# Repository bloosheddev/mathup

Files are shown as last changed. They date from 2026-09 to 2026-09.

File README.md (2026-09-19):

<h1 align="center">
  <picture>
    
  </picture>

<p>
  🔥 MathUp! Clock 🔥
</p>



</h1>

## 💀 Uniques Features!
X + Y = ??? (answer to snooze!!11!!1!)

## 💀 Overall Case!
| Top View | Bottom View |
| - | - |
|  | 

## ✍️ Schematic Image!


## 🖼️ PCB!

| 2D View | 3D View |
| - | - |
|  |  |

## Case Part!

| Lid | Case Chassis |
| - | - |
|  |  |
| The lid will be connected to the main case using strong adhesive to keep it minimalist and having a clean design | The PCB and all the main parts will be mounted on 3 mountings using M3 screws and for the LCD will be mounted on the case's dedicated slot for the LCD |

## Bill of Materials!
| Reference | Qty | Value |
| - | - | - |
| BZ1 | 1 | Buzzer |
| J1 | 1 | Conn_01x08_Pin |
| SW1,SW2,SW3,SW4 | 4 | SW_Push |
| U1 | 1 | XIAO-ESP32-C3-SMD |
| | 12 | MX-Style Keyboard Switches |
| | 4 | White Blank DSA Keycaps |
| | 1 | 2.25in TFT Screen |
| | 1 | 3.3V Piezo Buzzer |
| | 1 | 2.54mm 8 Pin Male Header |
| | 8 | 20cm Female-Female Jumper Wires |
| | 4 | M3x5x4 Heatset Inserts |
| | 4 | M3x8mm Screws |

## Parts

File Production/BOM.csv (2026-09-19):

Reference | Qty | Value | DNP | Exclude from BOM | Exclude from Board | Exclude from Simulation | Exclude from Position Files | Footprint | Datasheet
BZ1 | 1 | Buzzer |  |  |  |  | ${EXCLUDE_FROM_POS_FILES} | Buzzer_Beeper:Buzzer_12x9.5RM7.6
J1 | 1 | Conn_01x08_Pin |  |  |  |  | ${EXCLUDE_FROM_POS_FILES} | Connector_PinSocket_2.54mm:PinSocket_1x08_P2.54mm_Vertical
SW1,SW2,SW3,SW4 | 4 | SW_Push |  |  |  |  | ${EXCLUDE_FROM_POS_FILES} | Button_Switch_Keyboard:SW_Cherry_MX_1.00u_PCB
U1 | 1 | XIAO-ESP32-C3-SMD |  |  |  |  | ${EXCLUDE_FROM_POS_FILES} | Seeed_Studio_XIAO_Series:XIAO-ESP32-C3-DIP
 | 12 | MX-Style Keyboard Switches
 | 4 | White Blank DSA Keycaps
 | 1 | 2.25in TFT Screen
 | 1 | 3.3V Piezo Buzzer
 | 1 | 2.54mm 8 Pin Male Header
 | 8 | 20cm Female-Female Jumper Wires
 | 4 | M3x5x4 Heatset Inserts
 | 4 | M3x8mm Screws

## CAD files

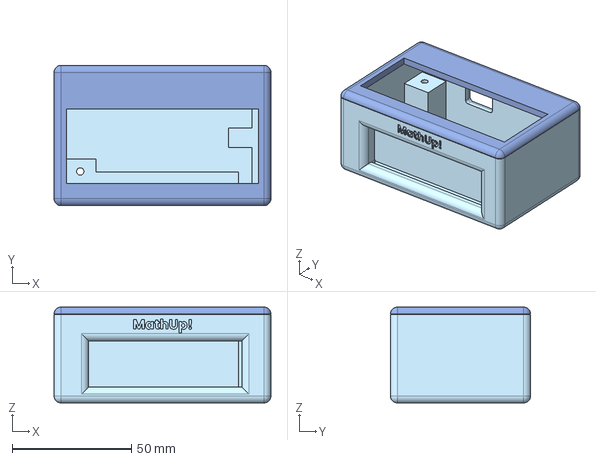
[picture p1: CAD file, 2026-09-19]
CAD/CASE_ONLY.step
91.0 x 58.9 x 40.2 mm

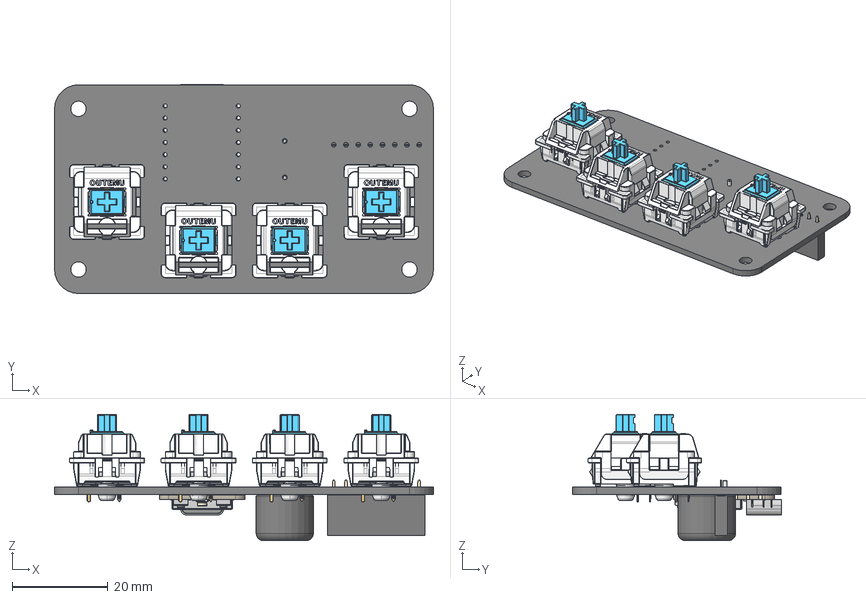
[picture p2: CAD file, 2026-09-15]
MUC_PCB/MUC_PCB.step
79.0 x 43.6 x 26.3 mm
BOTT x 4
PIN x 4
SPRIN x 4
CLICK x 4
RET x 4
TOP x 4
BOSS-EXTRUDE14_8_
BOSS-EXTRUDE7_4_
BOSS-EXTRUDE7_3_
BOSS-EXTRUDE14_4_
BOSS-EXTRUDE14_2_
BOSS-EXTRUDE14_11_
BOSS-EXTRUDE7_7_
BOSS-EXTRUDE14_9_
BOSS-EXTRUDE14_3_
BOSS-EXTRUDE14_7_
MIRROR2
BOSS-EXTRUDE14_5_
BOSS-EXTRUDE14_12_
BOSS-EXTRUDE7_8_
BOSS-EXTRUDE7_1_
BOSS-EXTRUDE14_10_
BOSS-EXTRUDE7_9_
BOSS-EXTRUDE14_6_
BOSS-EXTRUDE14_1_
BOSS-EXTRUDE7_6_
BOSS-EXTRUDE7_2_
CUT-EXTRUDE5
BOSS-EXTRUDE7_5_
U.FL Connector v1
Button (1) x 2
Shield
PinSocket_1x08_P2.54mm_Vertical
Buzzer_12x95RM76
MUC_PCB-unsaved-export-93sUD6_PCB

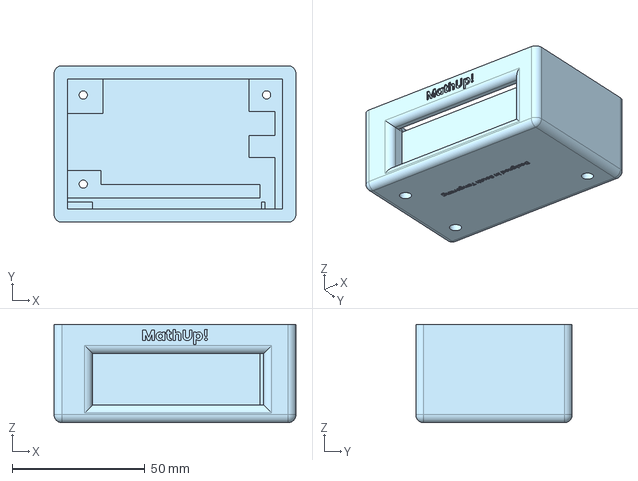
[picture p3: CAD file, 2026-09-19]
Production/CASE.step
91.0 x 58.8 x 37.0 mm

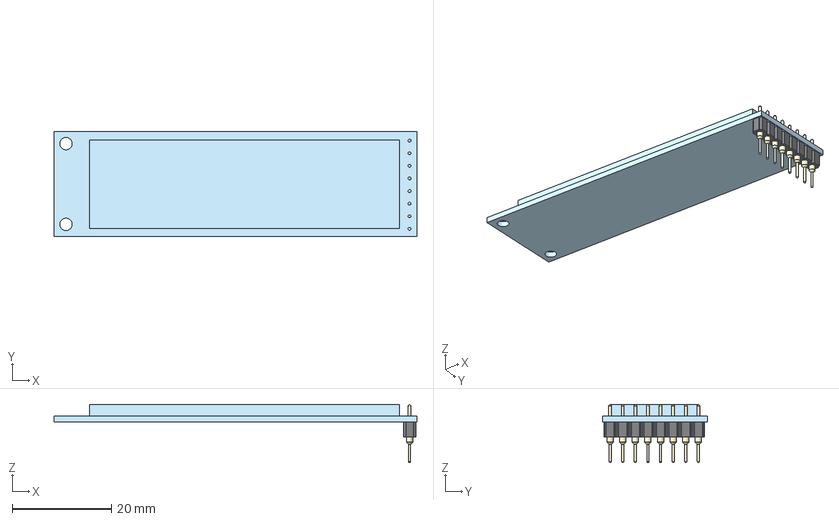
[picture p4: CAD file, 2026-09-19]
CAD/Display_ST7789.step
73.2 x 21.1 x 11.7 mm

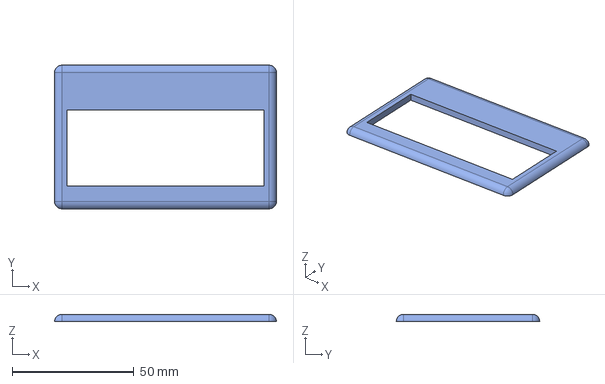
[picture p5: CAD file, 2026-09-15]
Production/LID.step
91.0 x 58.9 x 3.00 mm

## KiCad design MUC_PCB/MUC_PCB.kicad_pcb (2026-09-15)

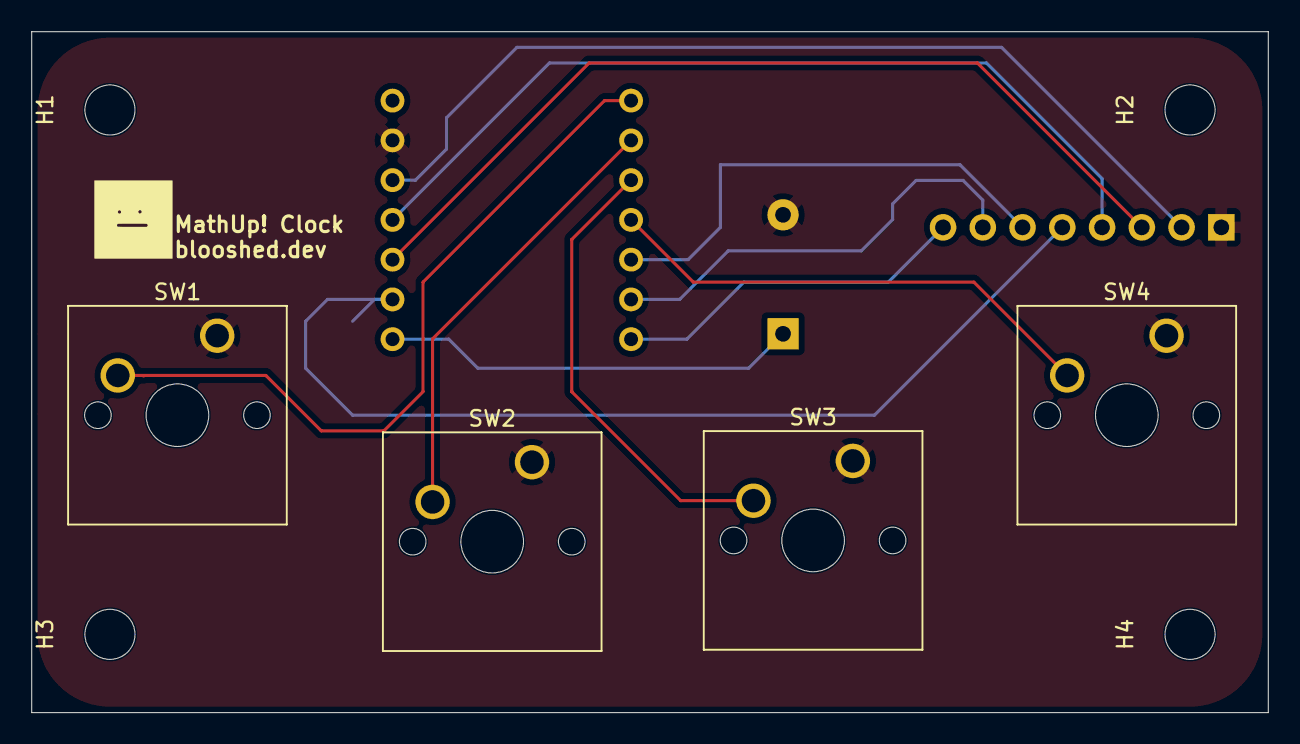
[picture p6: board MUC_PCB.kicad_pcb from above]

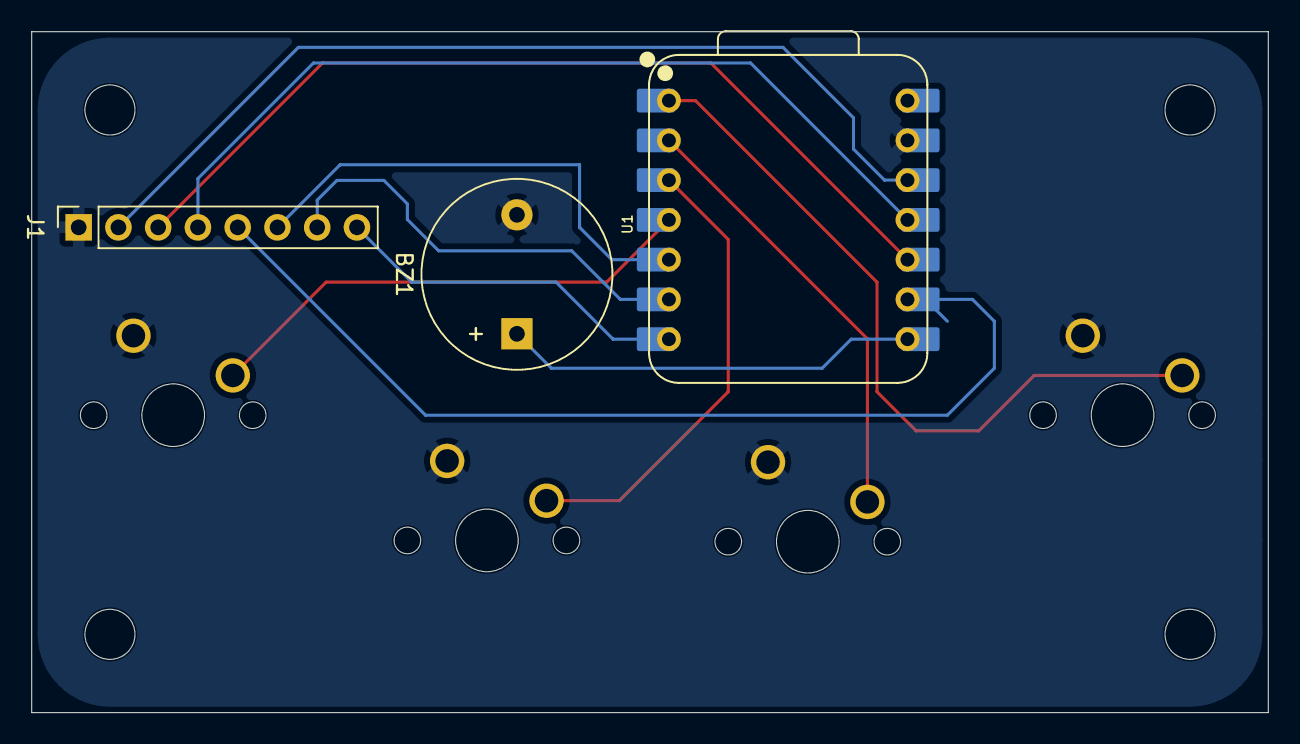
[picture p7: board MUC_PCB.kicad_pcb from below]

Board: 2 copper layers, 79.0 x 43.5 mm, 11 parts (3 on the bottom side), 13 nets.

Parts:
BZ1: Buzzer; Buzzer_12x9.5RM7.6
H1, H2, H3, H4: MountingHole; MountingHole_3.2mm_M3
J1: Conn_01x08_Pin; PinSocket_1x08_P2.54mm_Vertical
SW1, SW2, SW3, SW4: SW_Push; SW_Cherry_MX_1.00u_PCB
U1: XIAO-ESP32-C3-SMD; XIAO-ESP32-C3-DIP

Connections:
+3.3V: J1.2, U1.12 (3V3_OUT)
/BL: J1.8, U1.7 (D6)
/CS: J1.7, U1.6 (D5)
/DC: J1.6, U1.5 (D4)
/RST: J1.5, U1.9 (D8)
/SCL: J1.3, U1.10 (D9/BOOT)
/SDA: J1.4, U1.11 (D10)
GND: BZ1.2 (-), J1.1, SW1.1, SW2.1, SW3.1, SW4.1, U1.13 (GND)
unnamed: BZ1.1 (+), U1.8 (D7)
unnamed: SW1.2, U1.1 (D0)
unnamed: SW2.2, U1.2 (D1)
unnamed: SW3.2, U1.3 (D2)
unnamed: SW4.2, U1.4 (D3)

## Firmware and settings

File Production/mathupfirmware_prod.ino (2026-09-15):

#include <Adafruit_GFX.h>
#include <Adafruit_ST7789.h>
#include <SPI.h>
#include <ESP32Time.h>

// =========================
// Pin mapping from schematic
// =========================
const int TFT_SCLK = D9;
const int TFT_MOSI = D10;
const int TFT_RST  = D8;
const int TFT_DC   = D4;
const int TFT_CS   = D5;
const int TFT_BL   = D6;

const int BUZZER_PIN = D7; // BZ1+ -> D7, BZ1- -> GND

// Buttons (active LOW)
const int SW1_PIN = D0; // option 1 / back
const int SW2_PIN = D1; // option 2
const int SW3_PIN = D2; // option 3
const int SW4_PIN = D3; // option 4 / alarm list

const uint32_t DEBOUNCE_MS = 25;
const int SNOOZE_MINUTES = 5;

class MyST7789 : public Adafruit_ST7789 {
public:
  MyST7789(int8_t cs, int8_t dc, int8_t mosi, int8_t sclk, int8_t rst)
    : Adafruit_ST7789(cs, dc, mosi, sclk, rst) {}
  void setOffsets(uint8_t col, uint8_t row) {
    _colstart = _colstart2 = col;
    _rowstart = _rowstart2 = row;
  }
};

MyST7789 tft(TFT_CS, TFT_DC, TFT_MOSI, TFT_SCLK, TFT_RST);
ESP32Time rtc;

enum ScreenState { SCREEN_MAIN = 0, SCREEN_ALARM_LIST = 1, SCREEN_CHALLENGE = 2 };
ScreenState currentScreen = SCREEN_MAIN;

int lastMinute = -1;

// Alarm time
int alarmHour = 6;
int alarmMinute = 0;
bool alarmTriggeredThisMinute = false;

// Challenge state
int qX = 0, qY = 0, qAnswer = 0;
int options[4] = {0, 0, 0, 0};
int correctIndex = 0; // 0..3

// Buzzer timing (non-blocking beep pattern)
bool buzzerEnabled = false;
bool buzzerState = false;
uint32_t buzzerLastToggleMs = 0;
const uint16_t BUZZER_ON_MS = 120;
const uint16_t BUZZER_OFF_MS = 180;

struct ButtonState {
  uint8_t pin;
  bool stableState;
  bool lastRead;
  uint32_t lastChangeMs;
};

ButtonState buttons[4] = {
  {(uint8_t)SW1_PIN, HIGH, HIGH, 0},
  {(uint8_t)SW2_PIN, HIGH, HIGH, 0},
  {(uint8_t)SW3_PIN, HIGH, HIGH, 0},
  {(uint8_t)SW4_PIN, HIGH, HIGH, 0}
};

// ---------------- Lopaka screens ----------------
void drawScreen_3(void) { // Main
  tft.fillScreen(0x0);
  tft.setTextColor(0xFFFF);
  tft.setTextSize(7);
  tft.setTextWrap(false);
  tft.setCursor(41, 14);
  tft.print("12:00");

  tft.fillRect(218, 0, 51, 11, 0x4208);
  tft.setTextColor(0x0);
  tft.setTextSize(1);
  tft.setCursor(220, 2);
  tft.print("--------");

  tft.fillRect(150, 0, 63, 11, 0x4208);
  tft.setCursor(152, 2);
  tft.print("ALARM LIST");
}

void drawScreen_1(void) { // Alarm list
  tft.fillScreen(0x0);
  tft.fillRect(214, 0, 58, 15, 0xFFFF);
  tft.fillRect(145, 0, 58, 15, 0xFFFF);
  tft.fillRect(78, 0, 58, 15, 0xFFFF);
  tft.fillRect(10, 0, 58, 15, 0xFFFF);

  tft.setTextColor(0x0);
  tft.setTextWrap(false);
  tft.setTextSize(1);
  tft.setCursor(27, 4);
  tft.print("Back");

  tft.drawRect(56, 29, 173, 39, 0xFFFF);

  tft.setTextColor(0xFFFF);
  tft.setTextSize(4);
  tft.setCursor(84, 34);
  tft.print("06.00");

  tft.setTextSize(1);
  tft.setCursor(83, 20);
  tft.print("The alarm trigger on");
}

void drawScreen_2(void) { // Challenge
  tft.fillScreen(0x0);
  tft.setTextColor(0xFFFF);
  tft.setTextSize(4);
  tft.setTextWrap(false);
  tft.setCursor(24, 19);
  tft.print("x + y = __");

  tft.setTextSize(2);
  tft.setCursor(24, 52);
  tft.print("Answer to snooze!");

  tft.fillRect(213, 0, 58, 15, 0xFFFF);
  tft.fillRect(144, 0, 58, 15, 0xFFFF);
  tft.fillRect(77, 0, 58, 15, 0xFFFF);
  tft.fillRect(9, 0, 58, 15, 0xFFFF);

  tft.setTextColor(0x0);
  tft.setTextSize(1);
  tft.setCursor(236, 4); tft.print("00");
  tft.setCursor(167, 4); tft.print("00");
  tft.setCursor(100, 4); tft.print("00");
  tft.setCursor(32, 4);  tft.print("00");
}

// ---------------- Drawing helpers ----------------
void drawMainTime(int hh, int mm) {
  char buf[6];
  snprintf(buf, sizeof(buf), "%02d:%02d", hh, mm);
  tft.fillRect(35, 10, 180, 60, 0x0000);
  tft.setTextColor(0xFFFF);
  tft.setTextSize(7);
  tft.setCursor(41, 14);
  tft.print(buf);
}

void drawAlarmListTime() {
  char buf[6];
  snprintf(buf, sizeof(buf), "%02d.%02d", alarmHour, alarmMinute);
  tft.fillRect(80, 32, 90, 30, 0x0000);
  tft.setTextColor(0xFFFF);
  tft.setTextSize(4);
  tft.setCursor(84, 34);
  tft.print(buf);
}

void drawChallengeQuestionAndOptions() {
  char eq[20];
  snprintf(eq, sizeof(eq), "%d + %d = __", qX, qY);
  tft.fillRect(24, 19, 240, 30, 0x0000);
  tft.setTextColor(0xFFFF);
  tft.setTextSize(4);
  tft.setCursor(24, 19);
  tft.print(eq);

  // text x-positions for top 4 boxes (SW1..SW4)
  const int tx[4] = {32, 100, 167, 236};

  for (int i = 0; i < 4; i++) {
    char b[4];
    snprintf(b, sizeof(b), "%02d", options[i]);
    tft.setTextColor(0x0000);
    tft.setTextSize(1);
    tft.setCursor(tx[i], 4);
    tft.print(b);
  }
}

// ---------------- Buzzer ----------------
void buzzerOn() {
  buzzerEnabled = true;
}

void buzzerOff() {
  buzzerEnabled = false;
  buzzerState = false;
  digitalWrite(BUZZER_PIN, LOW);
}

void updateBuzzer() {
  if (!buzzerEnabled) return;

  uint32_t now = millis();
  uint16_t interval = buzzerState ? BUZZER_ON_MS : BUZZER_OFF_MS;
  if (now - buzzerLastToggleMs >= interval) {
    buzzerLastToggleMs = now;
    buzzerState = !buzzerState;
    digitalWrite(BUZZER_PIN, buzzerState ? HIGH : LOW);
  }
}

// ---------------- Challenge logic ----------------
bool existsInArray(int arr[], int n, int v) {
  for (int i = 0; i < n; i++) if (arr[i] == v) return true;
  return false;
}

int makeWrongAnswerNear(int correct) {
  int delta;
  do {
    delta = random(-8, 9); // -8..+8
  } while (delta == 0);
  int w = correct + delta;
  if (w < 0) w = 0;
  if (w > 99) w = 99;
  return w;
}

void generateChallenge() {
  // question range keeps answers in 0..99 two-digit display friendly
  qX = random(1, 20); // 1..19
  qY = random(1, 20); // 1..19
  qAnswer = qX + qY;

  for (int i = 0; i < 4; i++) options[i] = -1;
  correctIndex = random(0, 4);
  options[correctIndex] = qAnswer;

  for (int i = 0; i < 4; i++) {
    if (i == correctIndex) continue;
    int w;
    do {
      w = makeWrongAnswerNear(qAnswer);
    } while (w == qAnswer || existsInArray(options, 4, w));
    options[i] = w;
  }
}

void snoozeAlarm() {
  int total = alarmHour * 60 + alarmMinute + SNOOZE_MINUTES;
  total %= (24 * 60);
  alarmHour = total / 60;
  alarmMinute = total % 60;
}

// ---------------- Screen transitions ----------------
void enterMainScreen() {
  currentScreen = SCREEN_MAIN;
  drawScreen_3();
  int hh = rtc.getHour(true), mm = rtc.getMinute();
  drawMainTime(hh, mm);
  lastMinute = mm;
  buzzerOff();
}

void enterAlarmListScreen() {
  currentScreen = SCREEN_ALARM_LIST;
  drawScreen_1();
  drawAlarmListTime();
  buzzerOff();
}

void enterChallengeScreen() {
  currentScreen = SCREEN_CHALLENGE;
  drawScreen_2();
  generateChallenge();
  drawChallengeQuestionAndOptions();
  buzzerOn();
}

// ---------------- Input ----------------
void onButtonPressed(uint8_t pin) {
  if (currentScreen == SCREEN_MAIN) {
    if (pin == SW4_PIN) { // ALARM LIST
      enterAlarmListScreen();
      return;
    }
  } else if (currentScreen == SCREEN_ALARM_LIST) {
    if (pin == SW1_PIN) { // Back
      enterMainScreen();
      return;
    }
  } else if (currentScreen == SCREEN_CHALLENGE) {
    int picked = -1;
    if (pin == SW1_PIN) picked = 0;
    else if (pin == SW2_PIN) picked = 1;
    else if (pin == SW3_PIN) picked = 2;
    else if (pin == SW4_PIN) picked = 3;

    if (picked >= 0) {
      if (picked == correctIndex) {
        // success: snooze and exit challenge
        snoozeAlarm();
        enterMainScreen();
      } else {
        // wrong: keep alarm active + new random challenge
        generateChallenge();
        drawChallengeQuestionAndOptions();
      }
      return;
    }
  }
}

void updateButtons() {
  uint32_t now = millis();
  for (int i = 0; i < 4; i++) {
    bool reading = digitalRead(buttons[i].pin);
    if (reading != buttons[i].lastRead) {
      buttons[i].lastChangeMs = now;
      buttons[i].lastRead = reading;
    }
    if ((now - buttons[i].lastChangeMs) > DEBOUNCE_MS) {
      if (reading != buttons[i].stableState) {
        buttons[i].stableState = reading;
        if (buttons[i].stableState == LOW) onButtonPressed(buttons[i].pin);
      }
    }
  }
}

void setup() {
  Serial.begin(115200);
  randomSeed((uint32_t)esp_random());

  pinMode(TFT_BL, OUTPUT);
  digitalWrite(TFT_BL, LOW); // active-low backlight

  pinMode(BUZZER_PIN, OUTPUT);
  digitalWrite(BUZZER_PIN, LOW);

  pinMode(SW1_PIN, INPUT_PULLUP);
  pinMode(SW2_PIN, INPUT_PULLUP);
  pinMode(SW3_PIN, INPUT_PULLUP);
  pinMode(SW4_PIN, INPUT_PULLUP);

  tft.init(76, 284);
  tft.setOffsets(82, 18);
  tft.invertDisplay(false);
  tft.setRotation(1);

  rtc.setTime(0, 0, 12, 1, 1, 2026); // sec,min,hour,day,month,year
  enterMainScreen();
}

void loop() {
  updateButtons();
  updateBuzzer();

  int hh = rtc.getHour(true);
  int mm = rtc.getMinute();

  // Trigger challenge at alarm time (e.g., 06:00)
  if (hh == alarmHour && mm == alarmMinute) {
    if (!alarmTriggeredThisMinute && currentScreen != SCREEN_CHALLENGE) {
      alarmTriggeredThisMinute = true;
      enterChallengeScreen();
    }
  } else {
    alarmTriggeredThisMinute = false;
  }

  if (currentScreen == SCREEN_MAIN) {
    if (mm != lastMinute) {
      drawMainTime(hh, mm);
      lastMinute = mm;
    }
  }

  delay(5);
}

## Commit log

2026-09-15 minor: added pcb folder
2026-09-15 Added PCB
    [MUC_PCB.kicad_pcb, MUC_PCB.kicad_sch, MUC_PCB.step]
2026-09-15 Added CAD Design
    [MUC_Case.step]
2026-09-15 Added gerbers.zip
2026-09-15 Add firmware for alarm clock with challenges
    This file implements a firmware for a device with a graphical display, buttons, and a buzzer. It includes functionality for displaying time, managing alarms, and handling user input through buttons.
2026-09-15 Add mathup firmware for ESP32 with display and alarm
2026-09-15 Added case step file
    [CASE.step, LID.step]
